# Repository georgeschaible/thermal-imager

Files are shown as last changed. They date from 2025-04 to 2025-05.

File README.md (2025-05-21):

# thermal-imager
I built the DIY thermal imager designed by Ruslan Nadyrshin (rnadyrshin) and ran into a few issues that I thought I would share here. The project can be found at https://hackaday.io/project/189728-diy-pocket-thermal-imager and the firmware for version 1.1 of the device can be found at https://github.com/rnadyrshin/mlx90640_thermoimager_v1.1

I took this project on as an intro to electronics because of my intial assumption that it would be easy. In retrospect, many parts of this are easy but as a begginer, I had some fun troubleshooting parts that I could not get to work.

I purchased the lilygo ttgo t4 v1.3 (February 2025) and found that the screen would not initialize with the original code. I had to make edits to the ili9341.c file to get this to work.

Additionally, I could not get the SD card to succesfully mount so I had to make a few changes to the sd.c file as well.

Finally, as Ruslan points out, the text for the device is written in Russian so I thought I would share my python script for converting that to english. To use, save in the "main" directory and set the folder path in the python file (bottom of python code). Hopefully others find this helpful.

Here is the soldering map I made for version 1.1 of this project:
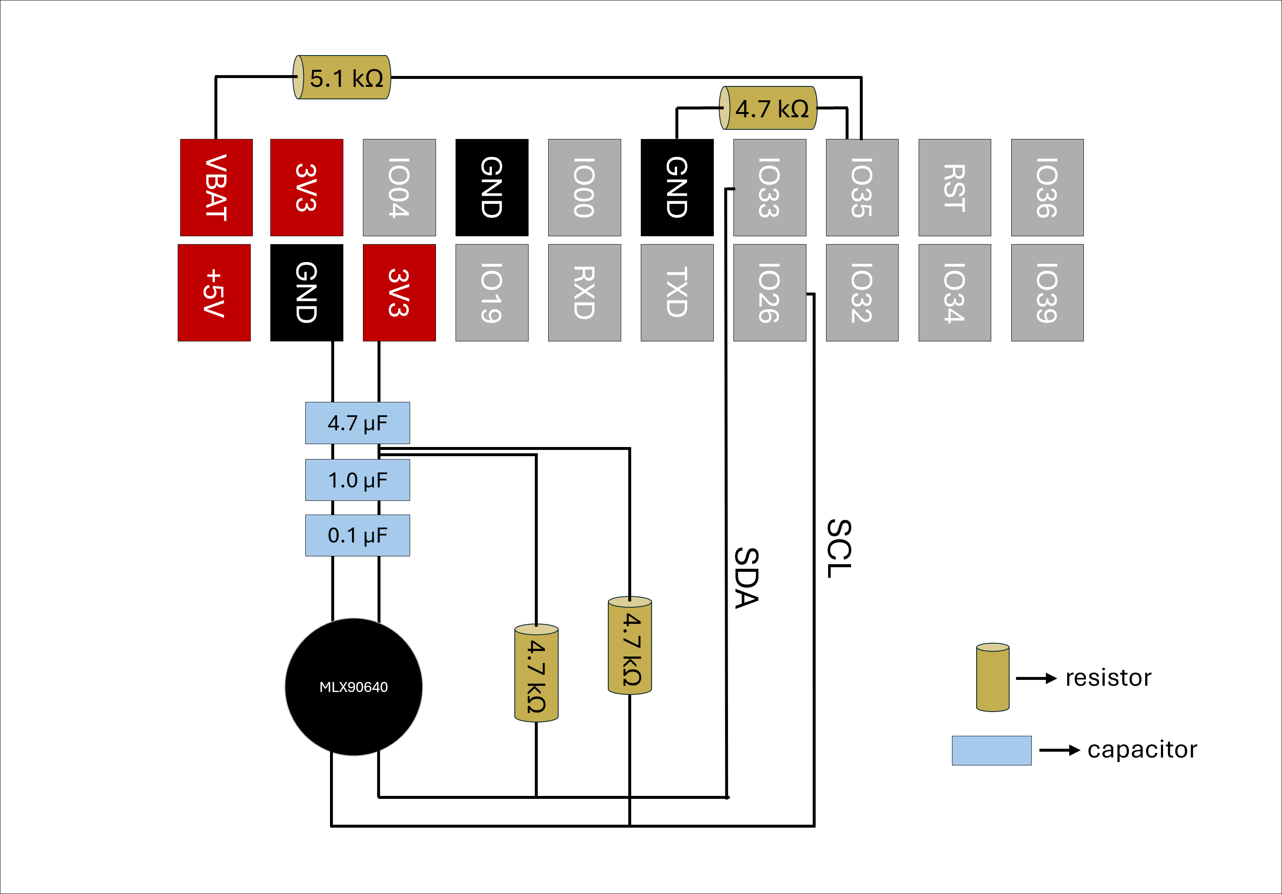
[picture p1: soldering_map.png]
Soldering map


I should mention that I found I did not need the low-pass noise filter so I did not use any capacitors for my build.

I have also added a folder (OpenSCAD) that has the source code and stl files for the camera case. The design is based off of what Ruslan shared on his hackaday page. OpenSCAD is a free modeling software that is easy to download and will allow you to make any adjustments you see fit for your set up. There are files for both the 2.4 and the 2.2 inch inch display. The 2.2 inch display is preferable because it can be mounted in each corner. This 3D design should fit the perfboard style that Ruslan built. I hope some folks find this helpful!









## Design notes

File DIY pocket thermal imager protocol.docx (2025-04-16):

DIY pocket thermal imager

https://hackaday.io/project/189728-diy-pocket-thermal-imager

Components

- 1 × Melexis MLX90640 sensor (or EVB90640-41 from DigiKey) – Thermal sensor
- 1 × LILYGO TTGO T4 v1.3 board – Microcontroller and display unit
- 1 × 3.7V 1800mAh 103449 LiPo Battery – Powers the device (get as thin as possible)
- 1 × JST 1.25mm 2 pin connector plug – Battery connector
- 1 × 280-point perfboard (thin) – Board for components
- 1 × 2x10 2.54mm pin connector – To connect the TTGO T4 to the perfboard
- 2 × 4.7 kΩ resistors – Pull-up resistors for both SDA and SCL lines
- 1 × 4.7 kΩ resistor – For measuring battery voltage (IO35 to GND)
- 1 × 5.1 kΩ resistor – For measuring battery voltage (IO35 to VBAT)
- 1 × 4.7 µF capacitor – Low pass noise filter for VDD and GND (optional)
- 1 × 1.0 µF capacitor – Low pass noise filter for VDD and GND (optional)
- 1 × 0.1 µF capacitor – Low pass noise filter for VDD and GND (optional)
- 2 × 2mm shrink wrap – For sealing soldered wires to battery
- 24 AWG wire – To run SDA and SCL to pins
- 1 × 0.3 mm solder
- 1 × 0.6 mm solder

Tools

- Fine point soldering iron
- Multimeter to check voltage
- Micro-USB cable (for programming & charging – must be able to pass data to computer)
- Espressif idf 4.4.3 (bash based software for flashing device)

MLX90640 design:

Pin # | Name | Description
1 | SDA | I²C serial data (input/output)
2 | VDD | Positive supply
3 | GND | Negative supply (Ground)
4 | SCL | I²C serial clock (input only)

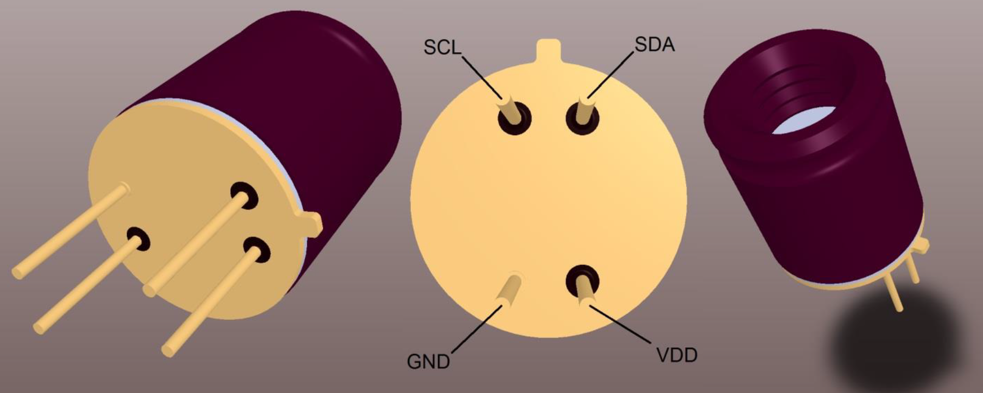
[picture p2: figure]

LILYGO T4 v1.3 pin map:

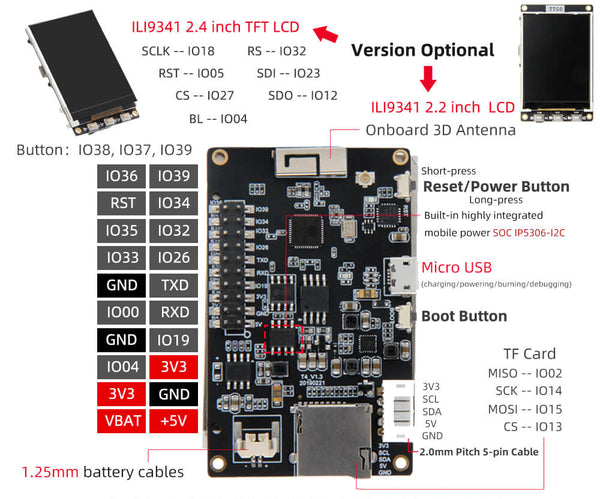
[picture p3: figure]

*This uses the ILI9341 driver, double check code

SPI connections:

SD Card Pin | ESP32 GPIO | Notes
MISO | GPIO2 | Data from SD card to ESP32
MOSI | GPIO15 | Data from ESP32 to SD card
SCK | GPIO14 | Clock signal
CS | GPIO13 | Chip Select (active low)

Assembly of hardware

1. Preparing the perfboard board
  a. Solder a 2x10 pin header to the perfboard board to connect the TTGO T4
    i. Solder the pin header as high as possible to allow extra room for battery
  b. Ensure that the pins will align to fit the device into the 3D printed container
    i. Use J to S columns on perfboard
2. Wire the MLX90640 Sensor
  a. Power connections:
    i. Solder VDD of the MLX90640 to 3.3V on the prototyping board
    ii. Solder GND to a ground rail on the prototyping board
  b. I²C Connections:
    i. Connect SCL from the sensor to IO26 on the TTGO T4
    ii. Connect SDA from the sensor to IO33 on the TTGO T4
  c. Pull-up resistors:
    i. Add 4.7 kΩ resistors between SCL and VDD, and SDA and VDD
3. Add the Low-Pass Filter (if needed, i.e. noise in thermal image)
  a. Place a 0.1 µF capacitor between VDD and GND near the sensor
  b. Place a 1.0 µF capacitor between VDD and GND near the sensor
  c. Place a 4.7 µF capacitor near the sensor on the prototyping board for additional stability

Wiring Schematic:

MLX90640 Pin | TTGO T4 Pin | Function
VDD | 3V3 | 3.3V power supply*
GND | GND | Ground
SCL | IO26 (SCL) | I²C Clock – use 4.7kΩ for pull-up resistor
SDA | IO33 (SDA) | I²C Data – use 4.7kΩ for pull-up resistor

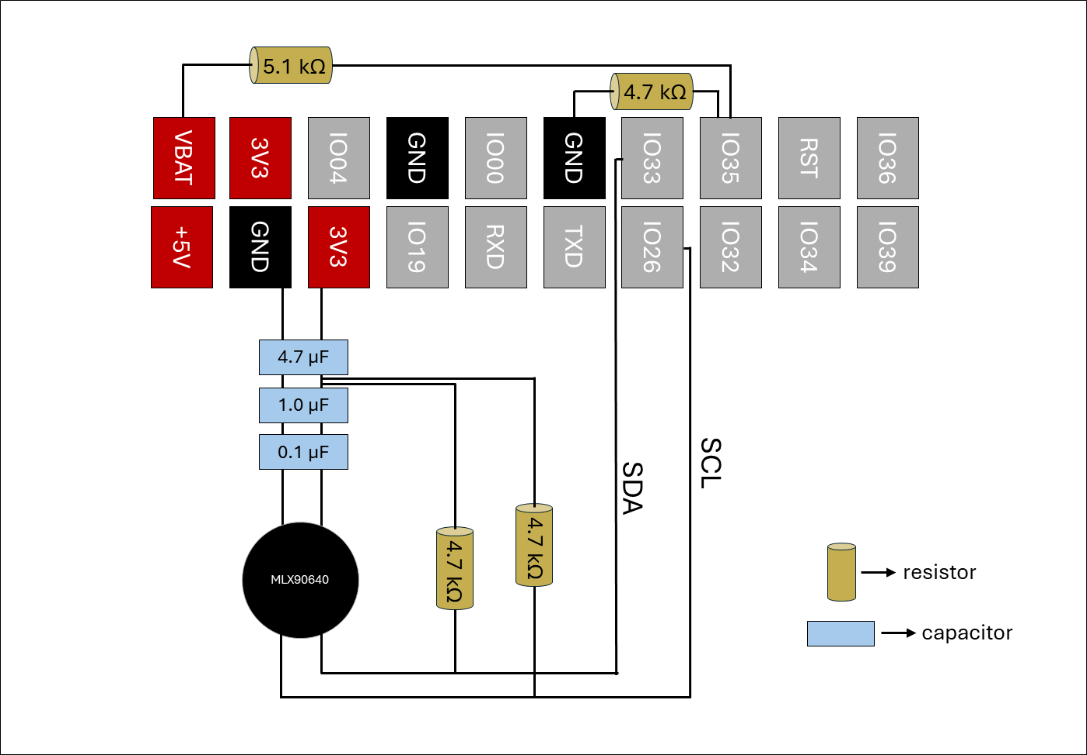
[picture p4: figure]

*Do NOT use the 5V pin of the TTGO T4

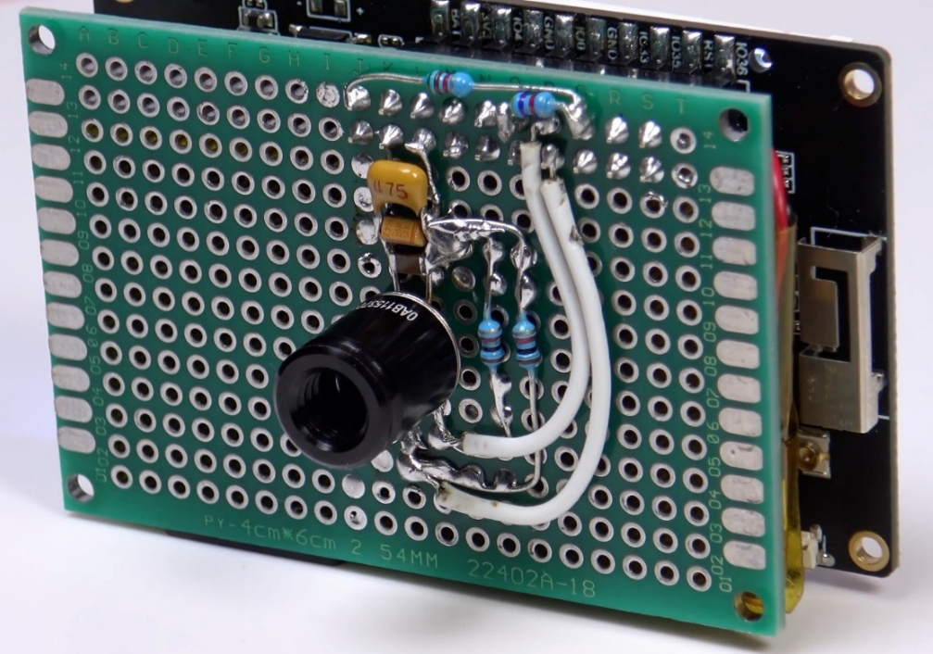
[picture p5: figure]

Photo credit: Ruslan Nadyrshin

4. Solder the JST connection to the batter
  a. Seal with shrink wrap to protect wire
5. Test connections
  a. Once the firmware is flashed and the device is powered on, use a multimeter set to 12V to test the GND and VDD connections and pull-ups to ensure the read 3.3V

Flash the firmware to the TTGO T4

The creator of this design wrote some amazing firmware that allows for .bmp images to be saved as well as .csv arrays of the thermal data. These are saved to the SD card which can then be opened on your computer. Overall, I am really impressed with the firmware and would use it for future iterations of this device. However, the firmware is written in Russian, so I did write a small python script to translate the Russian to English.

- Translate the Russian to English:
  - Save the python script into the “main” folder of the firmware
  - In bash, cd into the “main” folder of the firmware
  - Run: pip install googletrans==4.0.0-rc1
  - Run: python translate_russian.py
  - Remove the python file before building the firmware
1. Clone the project’s GitHub repository or download the firmware ZIP for V1.1
  a. https://github.com/rnadyrshin/mlx90640_thermoimager_v1.1/tree/a2679fc66f4ca5bb4e832fe65e93f84e03494f88
  b. I had to make a lot of edits to the code to get it to work for my device so ask me for my firmware if you get to this point.
2. Open the ESP IDF bash and cd into firmware directory
3. Run: idf.py build
  a. This will build the firmware for flashing
4. Run idf.py -p (Port) flash
  a. Replace “port” with the port your device is plugged into
5. Run idf.py -p (Port) monitor
  a. This allows you to monitor the device for errors or issues

Appendix:

LILYGO T4 specifications

MCU | ESP32
Flash | 4MB
PSRAM | 8MB
Wireless Connectivity | Wi-fi 802.11 b/g/n, BL V4.2+BLE
Programming Platform | Arduino-ide, Micropython
Serial chip | CH9102F QFN24
Display Optional | 2. 2
Onboard functions | Buttons: Boot+RST battery power detection
ILI9341 TFT LCD | Resolution 320x240
support 65K color display | 4-wire SPI interface
Working Power Supply | 3.3V
Driver IC | ILI9341
Support arduino library TFT_ espl | Support USB/LI-PO Battery
JST Connect type | JST GH 1. 25mm

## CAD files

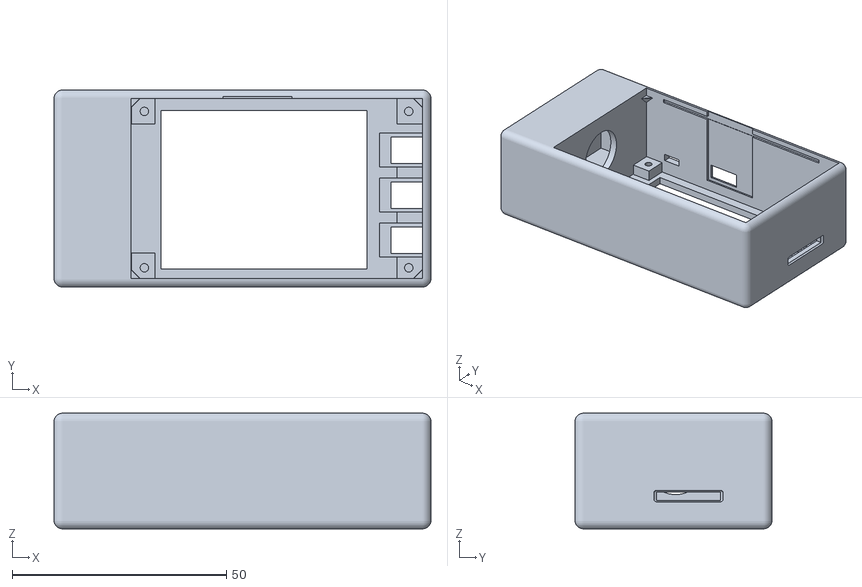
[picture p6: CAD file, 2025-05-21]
OpenSCAD_files/2.2_inch_display/2.2LCD_screen_design_v5.stl
88.0 x 46.0 x 27.0

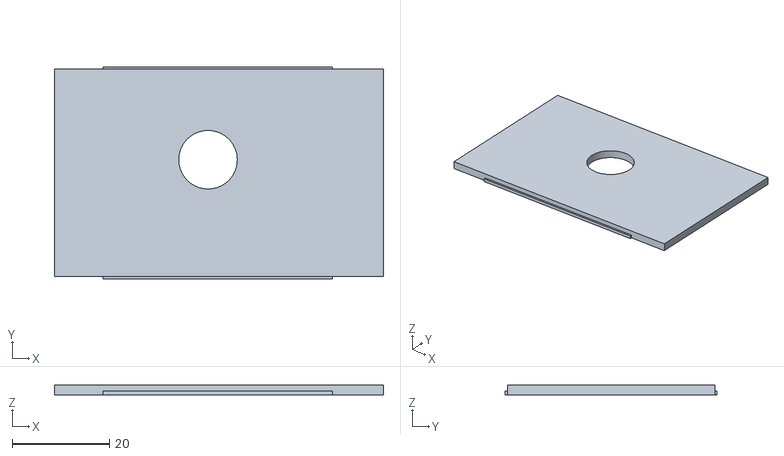
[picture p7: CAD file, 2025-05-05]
OpenSCAD_files/2.4_inch_display/Camera_cover_v2.stl
67.5 x 43.5 x 2.00

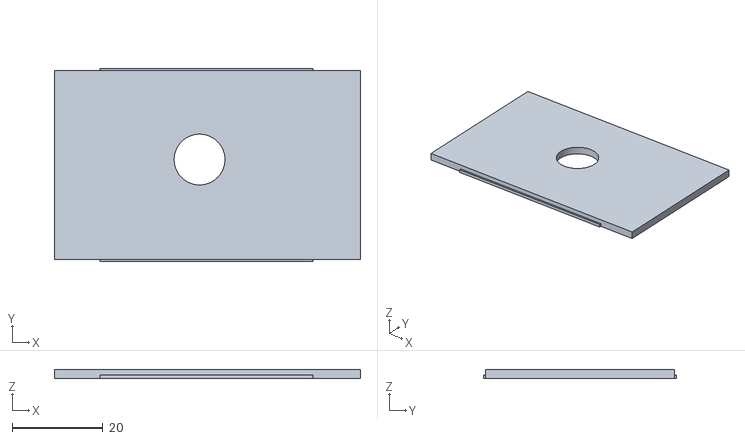
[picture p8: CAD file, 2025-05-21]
OpenSCAD_files/2.2_inch_display/2.2cm_camera_cover_v4.stl
67.5 x 42.6 x 2.00

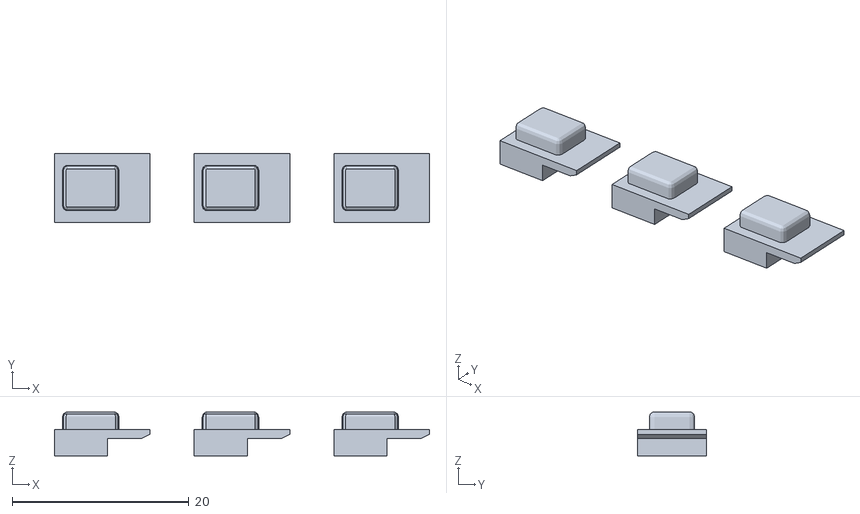
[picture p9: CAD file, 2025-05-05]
OpenSCAD_files/2.4_inch_display/Buttons_v3.stl
42.4 x 7.80 x 4.97

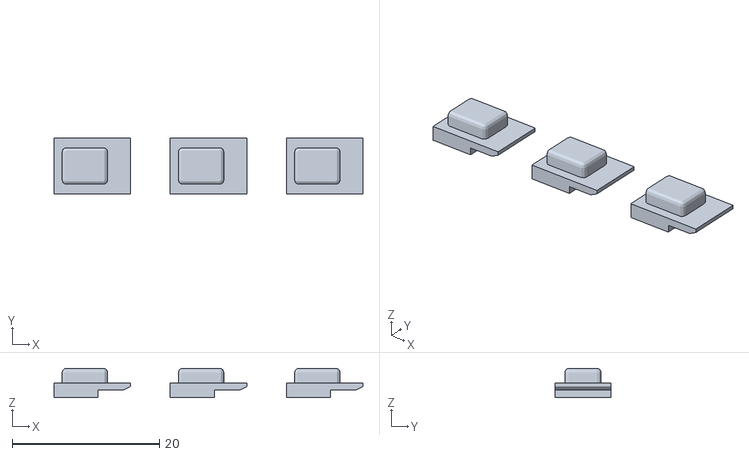
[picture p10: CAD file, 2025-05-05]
OpenSCAD_files/2.2_inch_display/Buttons_v6.stl
42.0 x 7.60 x 3.97

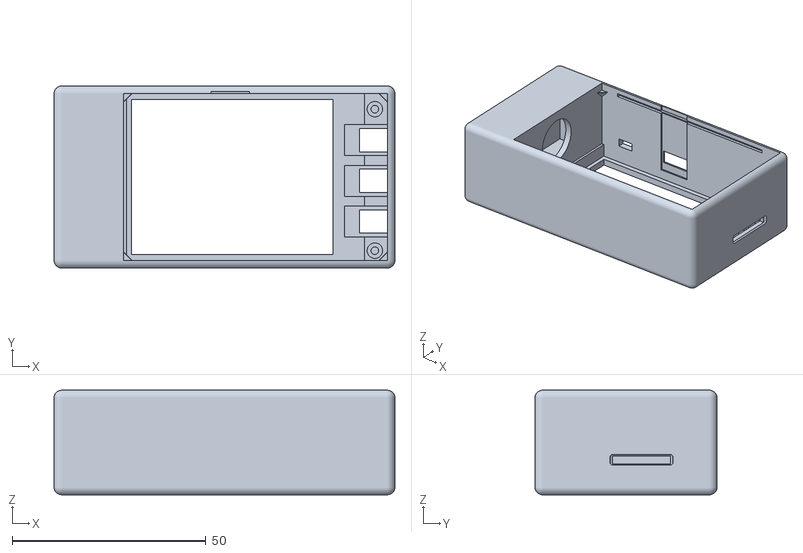
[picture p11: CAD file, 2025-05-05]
OpenSCAD_files/2.4_inch_display/2.4LCD_screen_design_v6.stl
88.0 x 47.0 x 27.0

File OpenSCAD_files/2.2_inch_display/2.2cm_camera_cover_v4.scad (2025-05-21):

$fa = 1;  
$fs = 0.4;  

difference() {
    cube([67.5, 41.6, 2]);
    
    translate([32, 22, -1])
        cylinder(h=4, r=5.6);

}

    // Indents on top inner long wall
    translate([10, -0.5, 0])
        cube([47, 0.7, 0.8]);

    translate([10, 41.4, 0])
        cube([47, 0.7, 0.8]);

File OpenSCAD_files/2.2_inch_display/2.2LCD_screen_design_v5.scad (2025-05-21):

$fa = 1;  
$fs = 0.4;  

// === Case dimensions ===
case_length = 72;   // X
case_width  = 46;   // Y
case_height = 25;   // Z
wall = 2;         // Wall thickness
rounding = 2;       // Radius for corner rounding

module rounded_box(size, radius) {
    difference() {
        minkowski() {
            cube([size[0] - 2*radius, size[1] - 2*radius, size[2] - radius]);
            translate([radius, radius, radius])
                sphere(r=radius, $fn=32);
        }
    }
}

difference() {
    
    // === Outer shell ===
    rounded_box([case_length, case_width, case_height], rounding);

    // === Hollow interior ===
    translate([wall, wall, wall])
        cube([
            case_length - 2 * wall,
            case_width  - 2 * wall,
            case_height + 1
        ]);

    // === LCD screen window ===
    translate([9, 4.2, -1])
        cube([48, 37, 4]);

    // === Button cutouts and indents ===
    translate([62.6, 7.8, -1])
        cube([7.6, 6.2, 4]);
    translate([60, 7, 1.1])
        cube([11, 8, 4.5]);

    translate([62.6, 18.3, -1])
        cube([7.6, 6.2, 4]);
    translate([60, 17.5, 1.1])
        cube([11, 8, 4.5]);

    translate([62.6, 28.8, -1])
        cube([7.6, 6.2, 4]);
    translate([60, 28, 1.1])
        cube([11, 8, 4.5]);


    // === Toggle switch wires ===
    translate([-2, 23.5, 15])
        rotate([0, 90, 0])
            cylinder(h=5, r=7);

    // === microSD slot ===
    translate([69, 19, 6.6])
        rotate([90, 0, 90])
            cube([15, 2, 4]);
    translate([73, 19, 8.4])
        rotate([-90, 0, 90])
            difference() {
            minkowski() {
                cube([15, 1.5, 1]);
                sphere(r=.6, $fn=24); 
        }
    }

    // === Micro USB port cutout ===
    translate([24.5, case_width - 3, 10])
        rotate([-90, 0, 0])
            cube([9, 4, 3]);
    translate([24, case_width, 10.5])
        rotate([-90, 0, 0])
        difference() {
        minkowski() {
            cube([10, 5, 2]);
            sphere(r=1, $fn=24); 
        }
    }
    
    // === Micro USB groove ===
    translate([23.5, 43.5, 5])
        cube([16, 1, 25]);
    
    // === Reset button ===
    translate([8.5, 43.5, 6])
        cube([5, 5, 2]);
    
    // Indents on top inner long wall
    translate([8, 1.5, 24.5])
        cube([55, 1, 1]);

    translate([8, 43.6, 24.5])
        cube([55, 1, 1]);

}

difference() {
    // === Toggle switch box ===
    translate([-16, 0, 0])
        rounded_box([20, 46, 25], rounding);
    
    // === Slice intrusion ===
    translate([2, 2, 2])
        cube([4,42,25]);

    // === Hollow toggle interior ===
    translate([-14, 3, 2])
        cube([22,41,23]);
        
    // === Toggle switch cutout ===
    translate([-16, 13, 8])
        cube([4, 20, 12]);
}


// === Square supports between buttons ===
translate([64.1, 15, 2])
    cube([6, 2.5, 3]);

translate([64.1, 25.5, 2])
    cube([6, 2.5, 3]);

// === Square supports and hollow screw posts ===
translate([64.1, wall, 1.5])
difference() {
    union() {
        translate([0, 0, 0.5]) cube([6, 5, 3]);
        translate([2.7, 2.5, 0]) cylinder(h=3, r=2);
    }
    translate([2.7, 2.5, -1.5]) cylinder(h=8, r=1);
}

translate([64.1, 39, 1.5])
difference() {
    union() {
        translate([0, -1, 0.5]) cube([6, 6, 3]);
        translate([2.7, 2, 0]) cylinder(h=2, r=2);
    }
    translate([2.7, 2, -1.5]) cylinder(h=8, r=1);
}

translate([2.1, wall, 1.5])
difference() {
    union() {
        translate([0, 0, 0.5]) cube([5.5, 6, 3]);
        translate([3, 2.5, 0]) cylinder(h=3, r=2);
    }
    translate([3, 2.5, -1.5]) cylinder(h=8, r=1);
}

translate([2.1, 39, 1.5])
difference() {
    union() {
        translate([0, -1, 0.5]) cube([5.5, 6, 3]);
        translate([3, 2, 0]) cylinder(h=3, r=2);
    }
    translate([3, 2, -1.5]) cylinder(h=8, r=1);
}

  
// Tetrahedron supports
// Bottom-left corner
translate([1.5, 1.5, 24.5])
hull() {
    translate([0, 0, 0]) sphere(0.1);
    translate([3, 0, 0]) sphere(0.1);
    translate([0, 3, 0]) sphere(0.1);
    translate([0, 0, -3]) sphere(0.1);
}

// Bottom-right corner
translate([70.5, 1.5, 24.5])
hull() {
    translate([0, 0, 0]) sphere(0.1);
    translate([-3, 0, 0]) sphere(0.1);
    translate([0, 3, 0]) sphere(0.1);
    translate([0, 0, -3]) sphere(0.1);
}

// Top-left corner
translate([1.5, 44.5, 24.5])
hull() {
    translate([0, 0, 0]) sphere(0.1);
    translate([3, 0, 0]) sphere(0.1);
    translate([0, -3, 0]) sphere(0.1);
    translate([0, 0, -3]) sphere(0.1);
}

// Top-right corner
translate([70.5, 44.5, 24.5])
hull() {
    translate([0, 0, 0]) sphere(0.1);
    translate([-3, 0, 0]) sphere(0.1);
    translate([0, -3, 0]) sphere(0.1);
    translate([0, 0, -3]) sphere(0.1);
}

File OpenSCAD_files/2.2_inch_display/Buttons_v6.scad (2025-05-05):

$fa = 1;
$fs = 0.4;

module button_insert() {
    difference() {
        // === Base rectangle ===
        cube([10.4, 7.6, 1]);

        // === Triangular prism ===
        translate([8.6, 9, -0.4])
            rotate([90, 0, 0])
            linear_extrude(height=12)
                polygon(points=[[0,0], [2,0], [2,1]]);
    }

    // === Bottom extension ===
    translate([0, 0, -1.0])
        cube([6, 7.6, 1.2]);

    // === Rounded top cap ===
    translate([1.7, 1.9, 1])
    minkowski() {
        cube([5, 3.8, 1.4]);
        sphere(r=0.6);
    }
}

// === Create 3 spaced parts ===
for (i = [0:2]) {
    translate([i * (10.8 + 5), 0, 0])
        button_insert();
}

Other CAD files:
OpenSCAD_files/2.4_inch_display/2.4LCD_screen_design_v6.scad
OpenSCAD_files/2.4_inch_display/Buttons_v3.scad
OpenSCAD_files/2.4_inch_display/Camera_cover_v2.scad

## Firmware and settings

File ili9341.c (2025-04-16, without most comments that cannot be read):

#include <stdio.h>
#include <stdlib.h>
#include <string.h>
#include <freertos/FreeRTOS.h>
#include <freertos/task.h>
#include <esp_system.h>
#include <soc/gpio_struct.h>
#include <driver/spi_master.h>
#include <driver/gpio.h>
#include <driver/ledc.h>
#include "ili9341.h"


#define MADCTL_MY  0x80  ///< Bottom to top
#define MADCTL_MX  0x40  ///< Right to left
#define MADCTL_MV  0x20  ///< Reverse Mode
#define MADCTL_ML  0x10  ///< LCD refresh Bottom to top
#define MADCTL_RGB 0x00  ///< Red-Green-Blue pixel order
#define MADCTL_BGR 0x08  ///< Blue-Green-Red pixel order
#define MADCTL_MH  0x04  ///< LCD refresh right to left



#define ILI9341_NOP        0x00     ///< No-op register
#define ILI9341_SWRESET    0x01     ///< Software reset register
#define ILI9341_RDDID      0x04     ///< Read display identification information
#define ILI9341_RDDST      0x09     ///< Read Display Status

#define ILI9341_SLPIN      0x10     ///< Enter Sleep Mode
#define ILI9341_SLPOUT     0x11     ///< Sleep Out
#define ILI9341_PTLON      0x12     ///< Partial Mode ON
#define ILI9341_NORON      0x13     ///< Normal Display Mode ON

#define ILI9341_RDMODE     0x0A     ///< Read Display Power Mode
#define ILI9341_RDMADCTL   0x0B     ///< Read Display MADCTL
#define ILI9341_RDPIXFMT   0x0C     ///< Read Display Pixel Format
#define ILI9341_RDIMGFMT   0x0D     ///< Read Display Image Format
#define ILI9341_RDSELFDIAG 0x0F     ///< Read Display Self-Diagnostic Result

#define ILI9341_INVOFF     0x20     ///< Display Inversion OFF
#define ILI9341_INVON      0x21     ///< Display Inversion ON
#define ILI9341_GAMMASET   0x26     ///< Gamma Set
#define ILI9341_DISPOFF    0x28     ///< Display OFF
#define ILI9341_DISPON     0x29     ///< Display ON

#define ILI9341_CASET      0x2A     ///< Column Address Set
#define ILI9341_PASET      0x2B     ///< Page Address Set
#define ILI9341_RAMWR      0x2C     ///< Memory Write
#define ILI9341_RAMRD      0x2E     ///< Memory Read

#define ILI9341_PTLAR      0x30     ///< Partial Area
#define ILI9341_MADCTL     0x36     ///< Memory Access Control
#define ILI9341_VSCRSADD   0x37     ///< Vertical Scrolling Start Address
#define ILI9341_PIXFMT     0x3A     ///< COLMOD: Pixel Format Set

#define ILI9341_FRMCTR1    0xB1     ///< Frame Rate Control (In Normal Mode/Full Colors)
#define ILI9341_FRMCTR2    0xB2     ///< Frame Rate Control (In Idle Mode/8 colors)
#define ILI9341_FRMCTR3    0xB3     ///< Frame Rate control (In Partial Mode/Full Colors)
#define ILI9341_INVCTR     0xB4     ///< Display Inversion Control
#define ILI9341_DFUNCTR    0xB6     ///< Display Function Control

#define ILI9341_PWCTR1     0xC0     ///< Power Control 1
#define ILI9341_PWCTR2     0xC1     ///< Power Control 2
#define ILI9341_PWCTR3     0xC2     ///< Power Control 3
#define ILI9341_PWCTR4     0xC3     ///< Power Control 4
#define ILI9341_PWCTR5     0xC4     ///< Power Control 5
#define ILI9341_VMCTR1     0xC5     ///< VCOM Control 1
#define ILI9341_VMCTR2     0xC7     ///< VCOM Control 2

#define ILI9341_RDID1      0xDA     ///< Read ID 1
#define ILI9341_RDID2      0xDB     ///< Read ID 2
#define ILI9341_RDID3      0xDC     ///< Read ID 3
#define ILI9341_RDID4      0xDD     ///< Read ID 4

#define ILI9341_GMCTRP1    0xE0     ///< Positive Gamma Correction
#define ILI9341_GMCTRN1    0xE1     ///< Negative Gamma Correction


// The LCD needs a bunch of command/argument values to be initialized. They are stored in this struct.
typedef struct
{
    uint8_t cmd;
    uint8_t data[16];
    uint8_t databytes; //No of data in data; bit 7 = delay after set; 0xFF = end of cmds.
} lcd_init_cmd_t;

static uint16_t ScreenBuff[ILI9341_TFTHEIGHT * ILI9341_TFTWIDTH];
//static uint16_t *ScreenBuff;

static spi_device_handle_t _spi;
static uint8_t rotation = 0;
static uint16_t _width, _height;


DRAM_ATTR static const lcd_init_cmd_t ili_init_cmds[] =
{
    // Power contorl B, power control = 0, DC_ENA = 1
    {0xCF, {0x00, 0x83, 0X30}, 3},
    // Power on sequence control,
    // cp1 keeps 1 frame, 1st frame enable
    // vcl = 0, ddvdh=3, vgh=1, vgl=2
    // DDVDH_ENH=1
    {0xED, {0x64, 0x03, 0X12, 0X81}, 4},
    // Driver timing control A,
    // non-overlap=default +1
    // EQ=default - 1, CR=default
    // pre-charge=default - 1
    {0xE8, {0x85, 0x01, 0x79}, 3},
    // Power control A, Vcore=1.6V, DDVDH=5.6V
    {0xCB, {0x39, 0x2C, 0x00, 0x34, 0x02}, 5},
    // Pump ratio control, DDVDH=2xVCl
    {0xF7, {0x20}, 1},
    // Driver timing control, all=0 unit
    {0xEA, {0x00, 0x00}, 2},
    // Power control 1, GVDD=4.75V
    {0xC0, {0x26}, 1},
    // Power control 2, DDVDH=VCl*2, VGH=VCl*7, VGL=-VCl*3
    {0xC1, {0x11}, 1},
    // VCOM control 1, VCOMH=4.025V, VCOML=-0.950V
    {0xC5, {0x35, 0x3E}, 2},
    // VCOM control 2, VCOMH=VMH-2, VCOML=VML-2
    {0xC7, {0xBE}, 1},
    // Memory access control, MX=MY=0, MV=1, ML=0, BGR=1, MH=0
    {0x36, {0x28}, 1},
    // Pixel format, 16bits/pixel for RGB/MCU interface
    {ILI9341_PIXFMT, {0x55}, 1},
    // Frame rate control, f=fosc, 70Hz fps
    {0xB1, {0x00, 0x1B}, 2},
    // Enable 3G, disabled
    {0xF2, {0x08}, 1},
    // Gamma set, curve 1
    {0x26, {0x01}, 1},
    // Positive gamma correction
    {0xE0, {0x1F, 0x1A, 0x18, 0x0A, 0x0F, 0x06, 0x45, 0X87, 0x32, 0x0A, 0x07, 0x02, 0x07, 0x05, 0x00}, 15},
    // Negative gamma correction
    {0XE1, {0x00, 0x25, 0x27, 0x05, 0x10, 0x09, 0x3A, 0x78, 0x4D, 0x05, 0x18, 0x0D, 0x38, 0x3A, 0x1F}, 15},
    // Column address set, SC=0, EC=0xEF
    {0x2A, {0x00, 0x00, 0x00, 0xEF}, 4},
    // Page address set, SP=0, EP=0x013F
    {0x2B, {0x00, 0x00, 0x01, 0x3f}, 4},
    // Memory write
    {0x2C, {0}, 0},
    // Entry mode set, Low vol detect disabled, normal display
    {0xB7, {0x07}, 1},
    // Display function control
    {0xB6, {0x0A, 0x82, 0x27, 0x00}, 4},
    // Sleep out
    {ILI9341_SLPOUT, {0}, 0x80},
    // Display on
    {ILI9341_DISPON, {0}, 0x80},
	{ILI9341_RAMWR, {0}, 0x80},
    {0, {0}, 0xff},
};


//==============================================================================
//Send a command to the LCD. Uses spi_device_transmit, which waits until the transfer is complete.
//==============================================================================
void lcd_cmd(const uint8_t cmd)
{
	esp_err_t ret;
    spi_transaction_t t;
    memset(&t, 0, sizeof(t));       //Zero out the transaction
    t.length = 8;                     //Command is 8 bits
    t.tx_buffer = &cmd;               //The data is the cmd itself
    t.user = (void*) 0;                //D/C needs to be set to 0
    ret = spi_device_transmit(_spi, &t);  //Transmit!
    assert(ret==ESP_OK);            //Should have had no issues.
}
//==============================================================================
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

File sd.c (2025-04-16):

#include <esp_vfs_fat.h>
#include <driver/sdmmc_host.h>
#include <driver/sdspi_host.h>
#include "../console/console.h"
#include "sdmmc_cmd.h"
#include "sd.h"

// #define USE_SPI_MODE

static sdmmc_card_t* card = NULL;

int sd_CardInit()
{
    // Ensure the SD card is unmounted if it's already mounted
    if (card) {
        esp_vfs_fat_sdmmc_unmount();
        card = NULL;
    }

#ifndef USE_SPI_MODE
    sdmmc_host_t host = SDMMC_HOST_DEFAULT();
    host.slot = SDMMC_HOST_SLOT_1;

    // Use 1-line SD mode
    sdmmc_slot_config_t slot_config = SDMMC_SLOT_CONFIG_DEFAULT();
    slot_config.width = 1;

    // Enable pull-ups for SD card lines
    gpio_set_pull_mode(15, GPIO_PULLUP_ONLY);   // CMD
    gpio_set_pull_mode(2, GPIO_PULLUP_ONLY);    // D0
    gpio_set_pull_mode(13, GPIO_PULLUP_ONLY);   // D3 
#else
    sdmmc_host_t host = SDSPI_HOST_DEFAULT();
    host.slot = VSPI_HOST; // HSPI_HOST
    host.max_freq_khz = 26000;

    sdspi_slot_config_t slot_config = SDSPI_SLOT_CONFIG_DEFAULT();
    slot_config.gpio_miso = 2;
    slot_config.gpio_mosi = 15;
    slot_config.gpio_sck  = 14;
    slot_config.gpio_cs   = 13;
    slot_config.dma_channel = 2;
#endif

    // Configure mounting options
    esp_vfs_fat_sdmmc_mount_config_t mount_config =
    {
        .format_if_mount_failed = false,
        .max_files = 5,
        .allocation_unit_size = 16 * 1024
    };

    // Attempt to mount SD card
    esp_err_t ret = esp_vfs_fat_sdmmc_mount("/sdcard", &host, &slot_config, &mount_config, &card);
    if (ret != ESP_OK)
    {
        card = NULL;
        if (ret == ESP_FAIL)
            console_printf(MsgError, "Failed to mount filesystem.\r\nIf you want the card to be formatted,\r\nset format_if_mount_failed = true.");
        else
            console_printf(MsgError, "Failed to initialize the card (%s).\r\nMake sure SD card lines have pull-up\r\nresistors in place.", esp_err_to_name(ret));
        return -1;
    }

    // Print SD card details
    sdmmc_card_print_info(stdout, card);
    return 0;
}


int8_t sd_GetFree(uint32_t *pFreeMb, uint32_t *pTotalMb)
{
	if (!card)
		return -1;

	FATFS *fs;
	DWORD fre_clust, fre_sect, tot_sect;

	// Get volume information and free clusters of drive 0
	int err = f_getfree("0:", &fre_clust, &fs);
	if (err)
		return -1;

	// Get total sectors and free sectors
	tot_sect = (fs->n_fatent - 2) * fs->csize;
	fre_sect = fre_clust * fs->csize;

	// Ó÷èòûâàåì ðàçìåð ñåêòîðà è ïåðåñ÷èòûâàåì â Ìá
	tot_sect /= 1024;
	tot_sect *= card->csd.sector_size;
	tot_sect /= 1024;
	fre_sect /= 1024;
	fre_sect *= card->csd.sector_size;
	fre_sect /= 1024;

	*pFreeMb = fre_sect;
	*pTotalMb = tot_sect;

	return 0;
}

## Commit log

2025-04-16 Add files via upload
    Protocol for device assembly
2025-04-25 Add files via upload
    OpenSCAD code for camera case with space for rocker toggle on/off switch. Still making some adjustments to code so I will update later.
    [2.4LCD_screen_design_v6.scad, Buttons_v3.scad, Camera_cover_v2.scad]
2025-05-05 Delete OpenSCAD_files directory
    Old files
    [2.4LCD_screen_design_v6.scad, Buttons_v3.scad, Camera_cover_v2.scad]
2025-05-21 Delete OpenSCAD_files directory
    Updating directory
    [2.2LCD_screen_design_v5.scad, 2.2LCD_screen_design_v5.stl, 2.2cm_camera_cover_v4.scad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]
